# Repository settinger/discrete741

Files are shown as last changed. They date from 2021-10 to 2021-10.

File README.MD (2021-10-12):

# MD741, a dis-integrated circuit

## A 741-style op-amp made of discrete components, DIP-8 size

This is a challenge posted by [Albert van Dalen](https://hackaday.io/project/177194-discrete-741-operational-amplifier-in-dil8) that is extremely silly (so, ideal for me). So, Evil Mad Scientist Labs famously [scaled up the old μA741 op-amp](https://shop.evilmadscientist.com/productsmenu/762), splitting it into discrete parts. Can it be scaled back down to DIP-8 size, but keeping the discrete parts?

More info on [Albert's personal site](https://www.avdweb.nl/div/misc2/discrete-741-operational-amplifier-in-dil8). I had to adapt the challenge a little bit; I found the SOT-723 transistors were still too big, so I switched to BJTs in the SOT-883L package (1.0mm by 0.6mm, a wee bit wider than an 0402 component). There are probably some more space savings to be gained by finding a cleverer part arrangement and by switching from KiCad's 0201 footprint to a more compact 0201 footprint.

Evil Mad Scientist Labs has a large 555 timer kit, also. It seemed only natural to tackle that one, too! [My approach to that challenge is here](https://github.com/settinger/discrete555).

TODO: Re-check design, order boards and parts if I'm feeling brave, order stencil if I'm not feeling _that_ brave, figure out how I'm going to power a ±15V op-amp without access to a benchtop power supply.

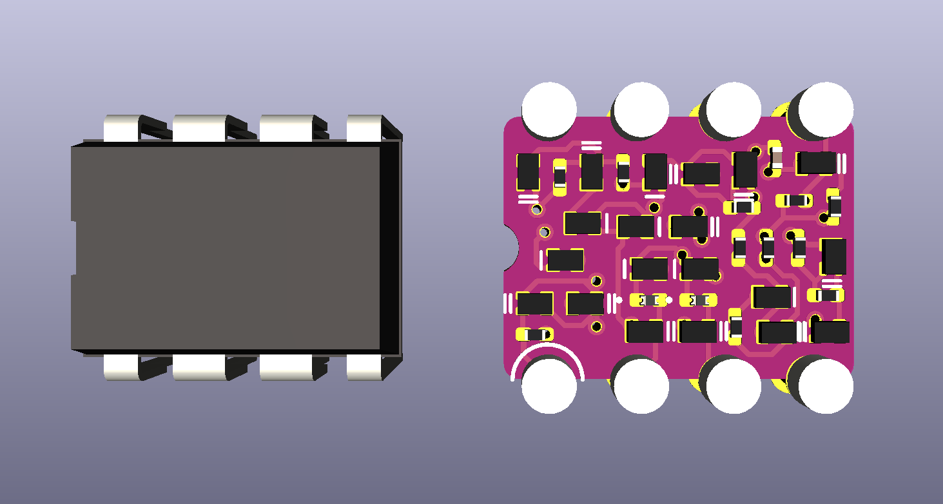
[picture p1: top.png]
3D render, top view looking down at a DIP-8 IC and the discrete 741 op-amp


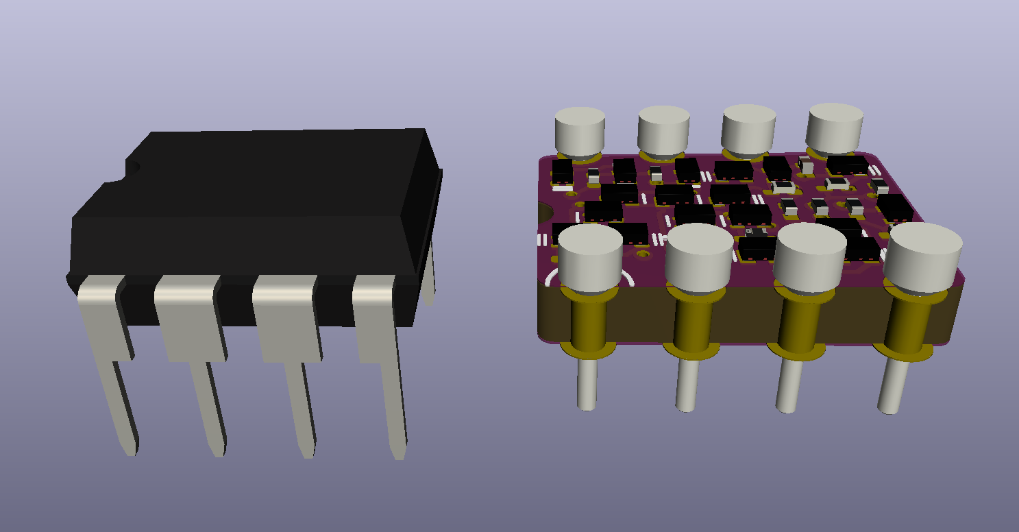
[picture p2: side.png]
3D render, side view looking at a DIP-8 IC and the discrete 741 op-amp


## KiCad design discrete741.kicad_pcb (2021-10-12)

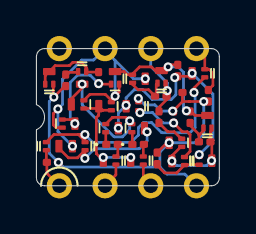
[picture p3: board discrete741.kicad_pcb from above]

Board: 2 copper layers, 10.2 x 7.6 mm, 35 parts (0 on the bottom side), 26 nets.

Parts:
C1: 33pF; C_0201_0603Metric
D1, D2: D_Schottky; D_0201_0603Metric
J1: DIP-8 Pins; DIP-8_W7.62mm
Q1, Q2, Q5, Q6, Q7, Q10, Q11, Q14, Q15, Q16, Q17, Q18, Q22: CET3904E; SOT-883L-alt
Q3, Q4, Q8, Q9, Q12, Q13, Q20: CET3906E; SOT-883L
R1, R2: 1kΩ; R_0201_0603Metric
R3, R12: 51kΩ; R_0201_0603Metric
R4, R7: 4.7kΩ; R_0201_0603Metric
R5: 39kΩ; R_0201_0603Metric
R8: 7.5kΩ; R_0201_0603Metric
R9: 24Ω; R_0201_0603Metric
R10, R11: 51Ω; R_0201_0603Metric

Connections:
In+: J1.3, Q1.1
In-: J1.2, Q2.1
unnamed: C1.1, Q13.3, Q14.1, Q15.3, Q18.3, R7.1
unnamed: C1.2, Q4.3, Q6.3, Q16.1, Q22.3
unnamed: D1.1, Q3.2
unnamed: D1.2, Q1.2
unnamed: D2.1, Q4.2
unnamed: D2.2, Q2.2
unnamed: Q1.3, Q2.3, Q8.1, Q8.3, Q9.1
unnamed: Q3.3, Q5.3, Q7.1
unnamed: Q5.1, Q6.1, Q7.2, R3.1
unnamed: Q10.1, Q11.1, Q11.3, R5.2
unnamed: Q10.2, R4.1
unnamed: Q3.1, Q4.1, Q9.3, Q10.3
unnamed: Q12.1, Q12.3, Q13.1, R5.1
unnamed: Q14.2, Q15.1, R9.1
unnamed: Q16.2, Q17.1, R12.1
unnamed: Q16.3, Q17.3, Q18.2, Q20.1, R8.2
unnamed: Q17.2, Q22.1, R11.1
unnamed: Q18.1, R7.2, R8.1
unnamed: Q20.2, R10.2
Offset1: J1.1, Q5.2, R1.1
Offset2: J1.5, Q6.2, R2.1
Output: J1.6, Q15.2, R9.2, R10.1
Vcc+: J1.7, Q7.3, Q8.2, Q9.2, Q12.2, Q13.2, Q14.3
Vcc-: J1.4, Q11.2, Q20.3, Q22.2, R1.2, R2.2, R3.2, R4.2, R11.2, R12.2

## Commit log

2021-10-02 Init commit
    [discrete741.kicad_pcb, discrete741.sch]
2021-10-02 cosmetic changes
    [discrete741.kicad_pcb]
2021-10-02 Added mark to distinguish NPN and PNP BJTs
    [discrete741.kicad_pcb, discrete741.sch]
2021-10-12 Added diodes per latest version of EMSL kit
    [discrete741.kicad_pcb, discrete741.sch]
2021-10-12 Update graphics
    [discrete741.kicad_pcb]
